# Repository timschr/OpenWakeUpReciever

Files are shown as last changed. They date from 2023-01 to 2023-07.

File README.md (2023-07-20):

# README - Open Wake-Up Receiver (WuR) Platform

## Table of Contents
1. [Introduction](#introduction)
2. [Getting Started](#getting-started)
3. [Documentation](#documentation)
4. [Usage](#usage)
5. [Contributing](#contributing)
6. [FAQ](#faq)
7. [License](#license)
8. [Acknowledgments](#acknowledgments)

## Introduction

Welcome to the world of Wake-up Receivers (WuRs)! 

Have you ever wished to have a tiny, ultra-low power device that can awaken your sensor nodes from sleep mode only when needed, saving power and reducing latency? WuR is the game-changer you've been waiting for!
The wake-up receiver's job is to keep a power-hungry device asleep and only wake it up when it's needed, saving energy.

This technology can be the brain of your next IoT project, enabling wireless sensor networks to function efficiently, conserve energy, and respond swiftly. From setting up a smart home system that wakes up when you're near, to implementing precision agriculture that responds to real-time changes in the environment, WuR opens up a world of possibilities.

WuR_Mac

## How to get started
Just head over to the [Hardware Guide](hardware/README.md) and go step by step from there.
If you feel at any point that your need more background or explation why thing where done the way the are, please refer to the [thesis](master_thesis_open_wake_up_receiver.pdf) this project is based on.

## How to get done

#### 1. Order Your PCB

The first step is to order your PCB (Printed Circuit Board). This will serve as the base for your wake-up receiver, where you'll attach and connect all your components. 

#### 2. Acquire Necessary Parts

Next, you'll need to gather all the other parts required for this project. This includes an 868MHz antenna a nano power comparator, and the PIC12LF1552 Microcontroller Unit (MCU). You can refer to the [Hardware Guide](hardware/README.md) for a more detailed list and where to get these parts.

#### 3. Assemble Your Receiver

Once you have your PCB and all the necessary parts, you can start putting your receiver together. Attach the components to your PCB and connect them according to the circuit design. Remember to double-check all your connections to ensure they're correct and secure.

#### 4. Program the MCU

With your circuit assembled, it's time to program your MCU. You'll need to flash the provided software onto the PIC12LF1552 using suitable PIC microcontroller programming software. More details on how to do this can be found in the [Software Guide](software/README.md).

#### 5. Acquire a Transmitter

Finally, you'll need a transmitter capable of sending OOK (On-Off Keying) signals at 868MHz. This will be used to send the wake-up signal to your receiver. The only requirements are that the transmitter can operate at this frequency and use OOK modulation.

### Prerequisites

#### Hardware:
  - PCB (Printed Circuit Board)
  - All the parts
  - 868 OOK Tranceiver
  - Breadboard
    
#### Tools:
- PICKit3: Programming to for PIC microcontroller. With some effort you can also use a simple arduino for this. Explaine e.g. here [https://github.com/jaromir-sukuba/a-p-prog])
- Soldering iron: You'll need this to attach components to your PCB. Not needed when you order the PCB preassembled.
- (Oscilloscope: This is optional but recommended for analyzing the signals in your circuit.)
- (NanoVNA: This is optional but handy to analyze the quality of the mathching network)

## Contributing

We warmly welcome contributions to this project. If you'd like to contribute, please fork the repository and make your changes. Then create a Pull Request to get your changes merged and reviewed.

We have a few guidelines for contributing, please check them out here: [CONTRIBUTING.md](./CONTRIBUTING.md)

## License

This project is licensed under the MIT License - see the [LICENSE.md](LICENSE.md) file for details

## Acknowledgments

I'd like to acknowledge the contributions of my academic advisors and the open-source community that has been pivotal in making this project what it is.

---

To create a detailed `CONTRIBUTING.md` file, include sections like:

1. Code of Conduct
2. How to report bugs or request features
3. How to set up the development environment
4. Code style guides
5. How to submit a Pull Request
6. What to expect after a Pull Request is submitted

In the `LICENSE.md` file, provide the full text of the license. If you're using MIT, you can find that [here](https://choosealicense.com/licenses/mit/).

The FAQ section should be updated as users interact with your project. Start with questions you think will be common, then add more as they come up.

Remember, READMEs are often the first thing people see when they come to your project, so make it engaging, informative, and welcoming.

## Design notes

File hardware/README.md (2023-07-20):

# Hardware Guide

This guide will walk you through the hardware aspects of creating your wake-up receiver, from understanding impedance matching, to ordering and assembling your PCB.

## Background: Impedance Matching

Impedance matching is a crucial concept in electronics that helps ensure maximum power transfer between components. In the context of our wake-up receiver, we need to ensure that the antenna and the circuitry on the PCB have the same impedance to prevent signal reflection and loss.  Trace width for the transmission line can be calculated with the [JLCPCB Impedance Caclulator](https://jlcpcb.com/pcb-impedance-calculator/) for different materials.

The need for accurate impedance matching is why there isn't much room for variations in the PCB design. Trace width, PCB material, thickness, and the number of layers all play a part in determining the overall impedance. We've chosen a 4-layer PCB as it offers easier impedance control.

## Transmitter

While our wake-up receiver (WuR) is all about listening for specific signals, it's important to remember that we also need a device to send these wake-up signals. 

Any device that supports On-Off Keying (OOK) at 868MHz could be used as a transmitter. In my project, I opted for the RFM95W module. What's really neat about this module is its support for LoRa, a low-power, long-range communication protocol. This could open up some fascinating possibilities, such as setting up a remote sensor network miles away via LoRa, and using WuRs for local communication.

Specifically, I used the [RFM95W shield for the Arduino Uno by Draguino](https://github.com/jgromes/RadioLib), which worked perfectly. This shield integrates well with the Arduino Uno, making it easy to create and transmit signals to our WuR.

An added bonus of the RFM95W module is that it's supported by the RadioLib library. If you're interested in doing more radio work with Arduino, I highly recommend checking out [RadioLib](https://github.com/jgromes/RadioLib). It's an incredibly helpful resource, packed full of tools and examples for various types of radio communication.

## Ordering Your PCB
With that said, let's start building. You will first need to order your PCB based on the provided [production files](production/). This guide will walk you through how to order it from JLCPCB, but you can also choose a different manufacturer as long as they have similar material characteristics.

### How to Order from JLCPCB:

1. Go to the [JLCPCB website](https://jlcpcb.com/)
2. Click on "Quote Now" or "Order Now"
3. In the new page, click on "Add your Gerber file" and upload the provided Gerber file
4. Scroll down to the "High-spec Options" and choose "Impedance Control: Yes"
5. Under "Layer stackup", select "JLC04161H-7628"

Then proceed with your order following the website's instructions.

## Ordering Parts

Next, you will need to order the other parts required for this project. These can be found at vendors like [Mouser](https://www.mouser.com/) or [Digikey](https://www.digikey.com/). The list of parts needed will be provided.

#### Parts List for 1 WuR
For the PCB:
Number of parts. Describtion, Spezification, Package
- 1 Inductor 2.2nH 0805
- 1 Inductor 3.3nH 0805
- 1 Capacitor 3.7pF 0805
- 1 Capacitor 5pF 0805
- 1 Capacitor 22pF 0805
- 1 Diode SMS7630-005LF
- 1 Diode XXX SMA
- 1 Resistor 2.2k 0805
- 1 Resistor XXX 0805
- 1 Capacitor 100n
- 1 Comparator TLV7031 SOT-23-5

For the breadboard:
- breadboard
- jumper wires
- PIC12LF1552

## Assembly

If you don't already have an 868MHz OOK transmitter, you'll need to purchase one. Once you have all your parts and your PCB, you can begin to put everything together on the breadboard.

Now, with your hardware assembled, you can move on to flashing the software onto your microcontroller. Please refer to the [Software Guide](../software/README.md) for instructions on how to do this.

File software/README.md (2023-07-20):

# Software Guide

This guide will walk you through how to upload the `wur_pic12lf1552_main.c` program to your PIC12LF1552 microcontroller using a PicKit3 programmer and MPLAB X IDE.

## Prerequisites 

Before starting, ensure that you have the following:

1. **MPLAB X IDE** installed on your computer. If you don't have it, you can download it from the [Microchip website](https://www.microchip.com/en-us/development-tools-tools-and-software/mplab-x-ide).

2. **PicKit3** programmer. This is the tool we'll use to transfer the program onto your microcontroller.

3. **wur_pic12lf1552_main.c** file. This is the program that will run on your PIC12LF1552 microcontroller.

## Steps 

Follow the steps below to upload the software:

1. **Connect Your PicKit3 Programmer**: Connect the PicKit3 programmer to your computer via USB. Then, connect the PicKit3 to your PIC12LF1552 microcontroller on your breadboard or PCB, ensuring that the ICSP (In-Circuit Serial Programming) pins line up correctly.

2. **Open MPLAB X IDE**: Launch the MPLAB X IDE software on your computer.

3. **Create a New Project**: Go to `File -> New Project`. Choose `Microchip Embedded -> Standalone Project` and click `Next`.

4. **Select Device**: In the dropdown menu, select `PIC12LF1552` and click `Next`.

5. **Select Tool**: Choose `PicKit3` in the dropdown menu and click `Next`.

6. **Select Compiler**: Choose the compiler you have installed. If you have none, download and install the `XC8` compiler from Microchip's website. Once installed, select it and click `Next`.

7. **Name and Choose Project Location**: Give your project a name and choose a location on your computer to save it. Click `Finish`.

8. **Add Your Source Code File**: Right-click on `Source Files` in the Project Window and choose `New -> main.c`. Copy the contents of `wur_pic12lf1552_main.c` into this new file. Save the file.

9. **Build the Project**: Click on the `Build` button (hammer icon) to compile your code. If the build is successful, you should see a `BUILD SUCCESSFUL` message in the Output Window.

10. **Program the MCU**: Click on the `Make and Program Device Main Project` button (the icon with an arrow pointing towards the chip) to upload the compiled program onto your PIC12LF1552 microcontroller.

If you encounter any issues, refer to the MPLAB X IDE's troubleshooting guide or Microchip's support forums.

## Understanding the Software
In this program, we're using a simple two-channel system to handle our wake-up signals that are connected to the `RA0` pin (data) and `RA2` pin (preamble). The first channel, `RA2`, is used to detect when a signal starts - this is called the preamble. When `RA2` detects a signal, it activates the second channel, `RA0`.

`RA0` is where we receive the actual data of the signal. Once `RA2` has detected a signal and activated `RA0`, the program starts measuring the time between signals on `RA0`. This is our data - specifically, it's an 'address' that tells the microcontroller whether it should wake up or ignore the signal.

## Adapting the code
Keeping the program simple is critical because we're working with a small 8-bit microcontroller. This microcontroller isn't very powerful, so if the program gets too complex, it might start to slow down or experience delays. That's why we're just using these two channels and a timer to handle our wake-up signals.

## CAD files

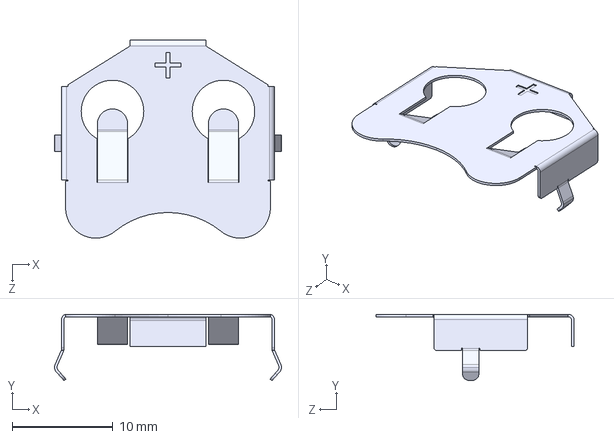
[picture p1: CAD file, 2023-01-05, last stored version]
ESP32-Power-Board/part_libs/BAT-HLD-005-THM/BAT-HLD-005-THM.step
22.5 x 6.59 x 19.6 mm

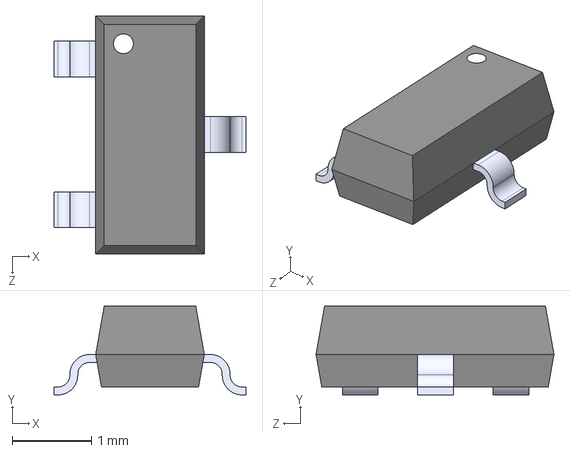
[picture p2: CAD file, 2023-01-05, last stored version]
ESP32-Power-Board/part_libs/DMP1045U/DMP1045U.step
2.42 x 1.12 x 3.00 mm

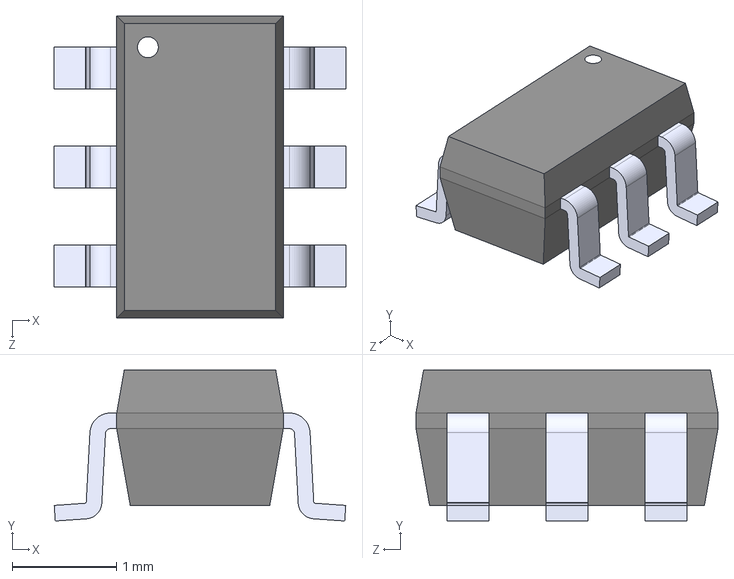
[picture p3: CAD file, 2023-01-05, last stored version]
ESP32-Power-Board/part_libs/DW01A/DW01A--3DModel-STEP-56544.STEP
2.80 x 1.45 x 2.90 mm

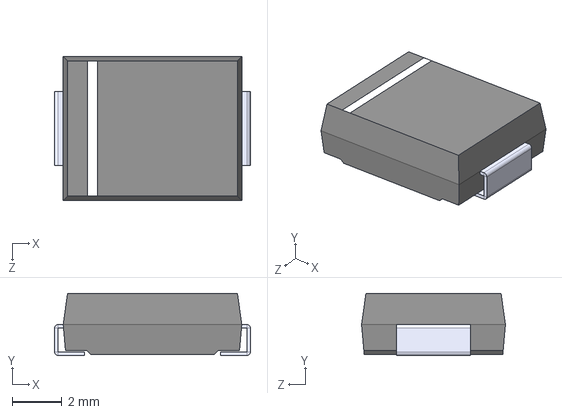
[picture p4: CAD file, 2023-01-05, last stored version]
ESP32-Power-Board/part_libs/SS34/SS34.step
7.90 x 2.50 x 5.80 mm

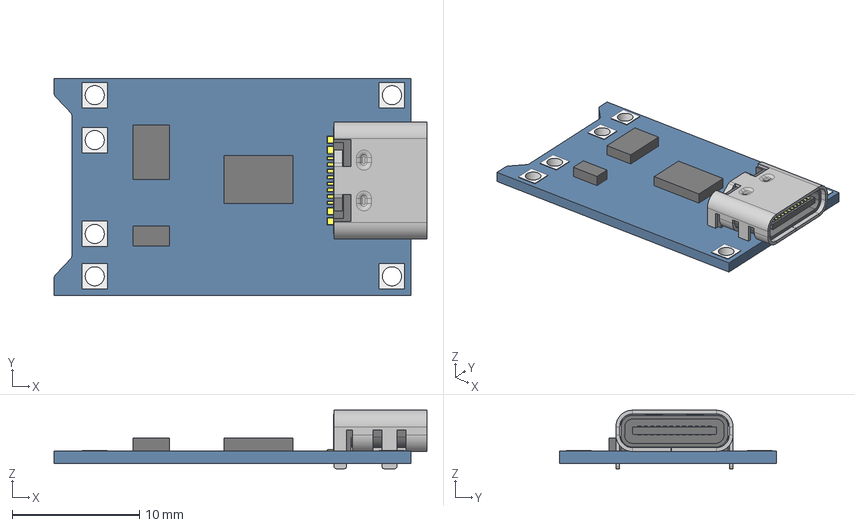
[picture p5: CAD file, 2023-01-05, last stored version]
ESP32-Power-Board/part_libs/TP4056/TP4056.step
29.3 x 17.0 x 4.60 mm

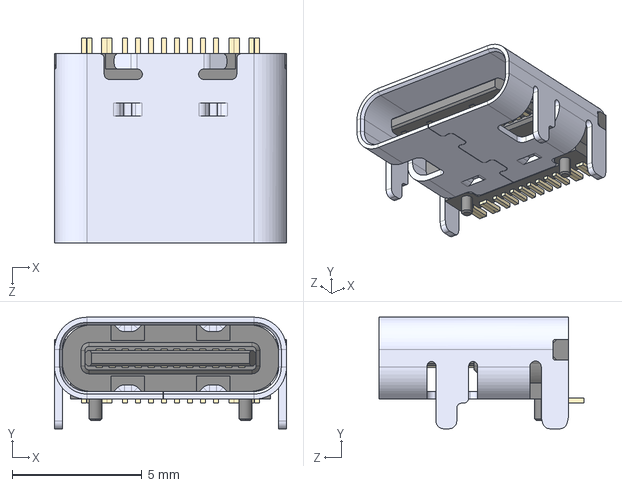
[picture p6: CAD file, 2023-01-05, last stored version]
ESP32-Power-Board/part_libs/TYPE-C-31-M-12/TYPE-C-31-M-12.step
8.94 x 4.30 x 7.90 mm

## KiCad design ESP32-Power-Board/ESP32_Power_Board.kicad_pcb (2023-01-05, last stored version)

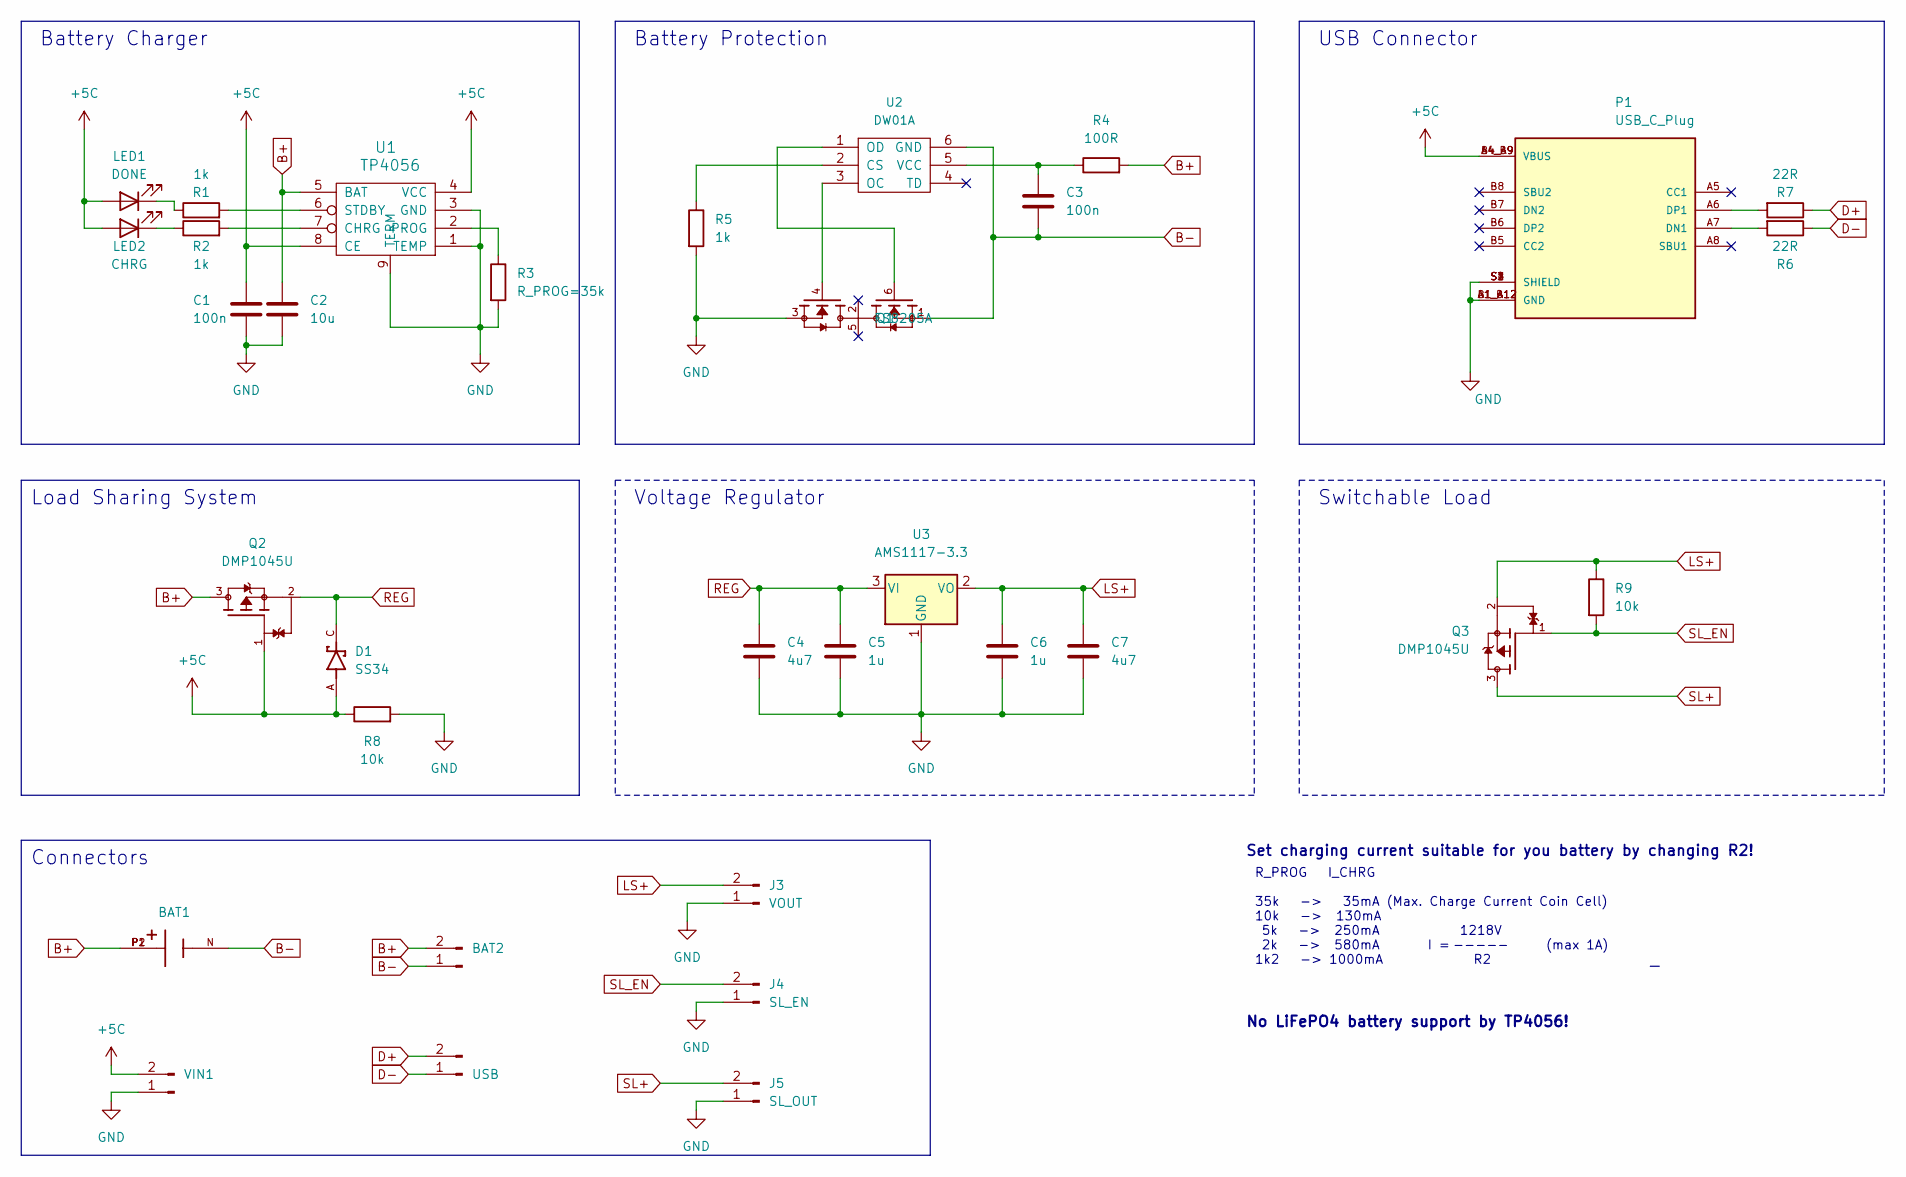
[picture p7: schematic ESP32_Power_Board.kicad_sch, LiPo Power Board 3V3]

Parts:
BAT1: BAT-HLD-005-THM; BAT_BAT-HLD-005-THM; PARTREV A
BAT2: BAT; JST_PH_B2B-PH-K_1x02_P2.00mm_Vertical
C1, C3: 100n; C_0805_2012Metric
C2: 10u; C_0805_2012Metric
C4, C7: 4u7; C_0805_2012Metric
C5, C6: 1u; C_0805_2012Metric
D1: SS34; DIOM7959X265N; PARTREV 31 Aug 2016
J3: VOUT; PinHeader_1x02_P2.54mm_Vertical
J4: SL_EN; PinHeader_1x02_P2.54mm_Vertical
J5: SL_OUT; PinHeader_1x02_P2.54mm_Vertical
LED1: DONE; LED_0805_2012Metric
LED2: CHRG; LED_0805_2012Metric
P1: USB_C_Plug; HRO_TYPE-C-31-M-12; PARTREV 2020.12.08
Q1: FS8205A; SOT95P280X145-6N; PARTREV 1.9
Q2, Q3: DMP1045U; SOT91P240X110-3N; PARTREV 7 - 2
R1, R2, R5: 1k; R_0805_2012Metric
R3: R_PROG=35k; R_0805_2012Metric
R4: 100R; R_0805_2012Metric
R6, R7: 22R; R_0805_2012Metric
R8, R9: 10k; R_0805_2012Metric
U1: TP4056; SOP127P600X175-9N
U2: DW01A; SOT23-6
U3: AMS1117-3.3; SOT-223-3_TabPin2
USB1: USB; PinSocket_1x02_P2.54mm_Vertical
VIN1: +VIN-; PinHeader_1x02_P2.54mm_Vertical

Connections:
+5C: C1.1, D1.A, LED1.2 (A), LED2.2 (A), P1.A4_B9 (VBUS), P1.B4_A9 (VBUS), Q2.1, R8.1, U1.4 (VCC), U1.8 (CE), VIN1.2
B+: BAT1.P1, BAT1.P2, BAT2.2, C2.1, Q2.3, R4.2, U1.5 (BAT)
B-: BAT1.N, BAT2.1, C3.2, Q1.1, U2.6 (GND)
D+: R7.1, USB1.2
D-: R6.1, USB1.1
GND: C1.2, C2.2, C4.2, C5.2, C6.2, C7.2, J3.1, J4.1, J5.1, P1.A1_B12 (GND), P1.B1_A12 (GND), P1.S1 (SHIELD), P1.S2 (SHIELD), P1.S3 (SHIELD), P1.S4 (SHIELD), Q1.3, R3.2, R5.2, R8.2, U1.1 (TEMP), U1.3 (GND), U1.9 (TERM), U3.1 (GND), VIN1.1; also elsewhere on the board
LS+: C6.1, C7.1, J3.2, Q3.2, R9.1, U3.2 (VO)
unnamed: C3.1, R4.1, U2.5 (VCC)
unnamed: LED1.1 (K), R1.1
unnamed: LED2.1 (K), R2.1
unnamed: P1.A6 (DP1), R7.2
unnamed: P1.A7 (DN1), R6.2
unnamed: R1.2, U1.6 (STDBY)
unnamed: R2.2, U1.7 (CHRG)
unnamed 14: R3.1, U1.2 (PROG); also elsewhere on the board
unnamed: R5.1, U2.2 (CS)
unnamed: Q1.6, U2.1 (OD)
unnamed: Q1.4, U2.3 (OC)
REG: C4.1, C5.1, D1.C, Q2.2, U3.3 (VI)
SL+: J5.2, Q3.3
SL_EN: J4.2, Q3.1, R9.2

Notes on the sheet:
Load Sharing System
USB Connector
1218V ----- R2
Switchable Load
Connectors
No LiFePO4 battery support by TP4056!
Battery Protection
Voltage Regulator
R_PROG I_CHRG 35k -> 35mA (Max. Charge Current Coin Cell) 10k -> 130mA 5k -> 250mA 2k -> 580mA I = (max 1A) 1k2 -> 1000mA
Battery Charger
Set charging current suitable for you battery by changing R2!

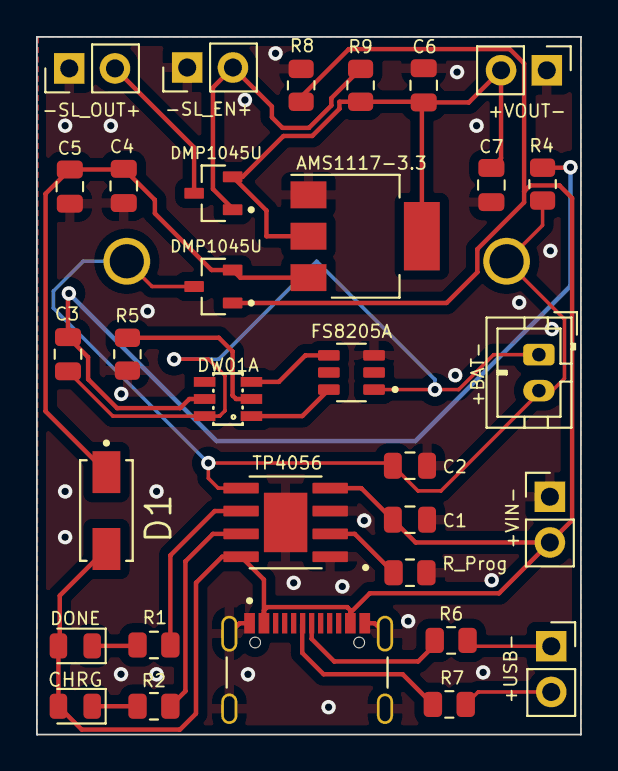
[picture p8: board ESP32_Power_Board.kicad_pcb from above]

Board: 2 copper layers, 30.2 x 38.8 mm, 33 parts (1 on the bottom side), 21 nets.

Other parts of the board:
R_Prog: 35k; R_0805_2012Metric

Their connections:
GND: R_Prog.2; also elsewhere on the board
unnamed 14: R_Prog.1; also elsewhere on the board

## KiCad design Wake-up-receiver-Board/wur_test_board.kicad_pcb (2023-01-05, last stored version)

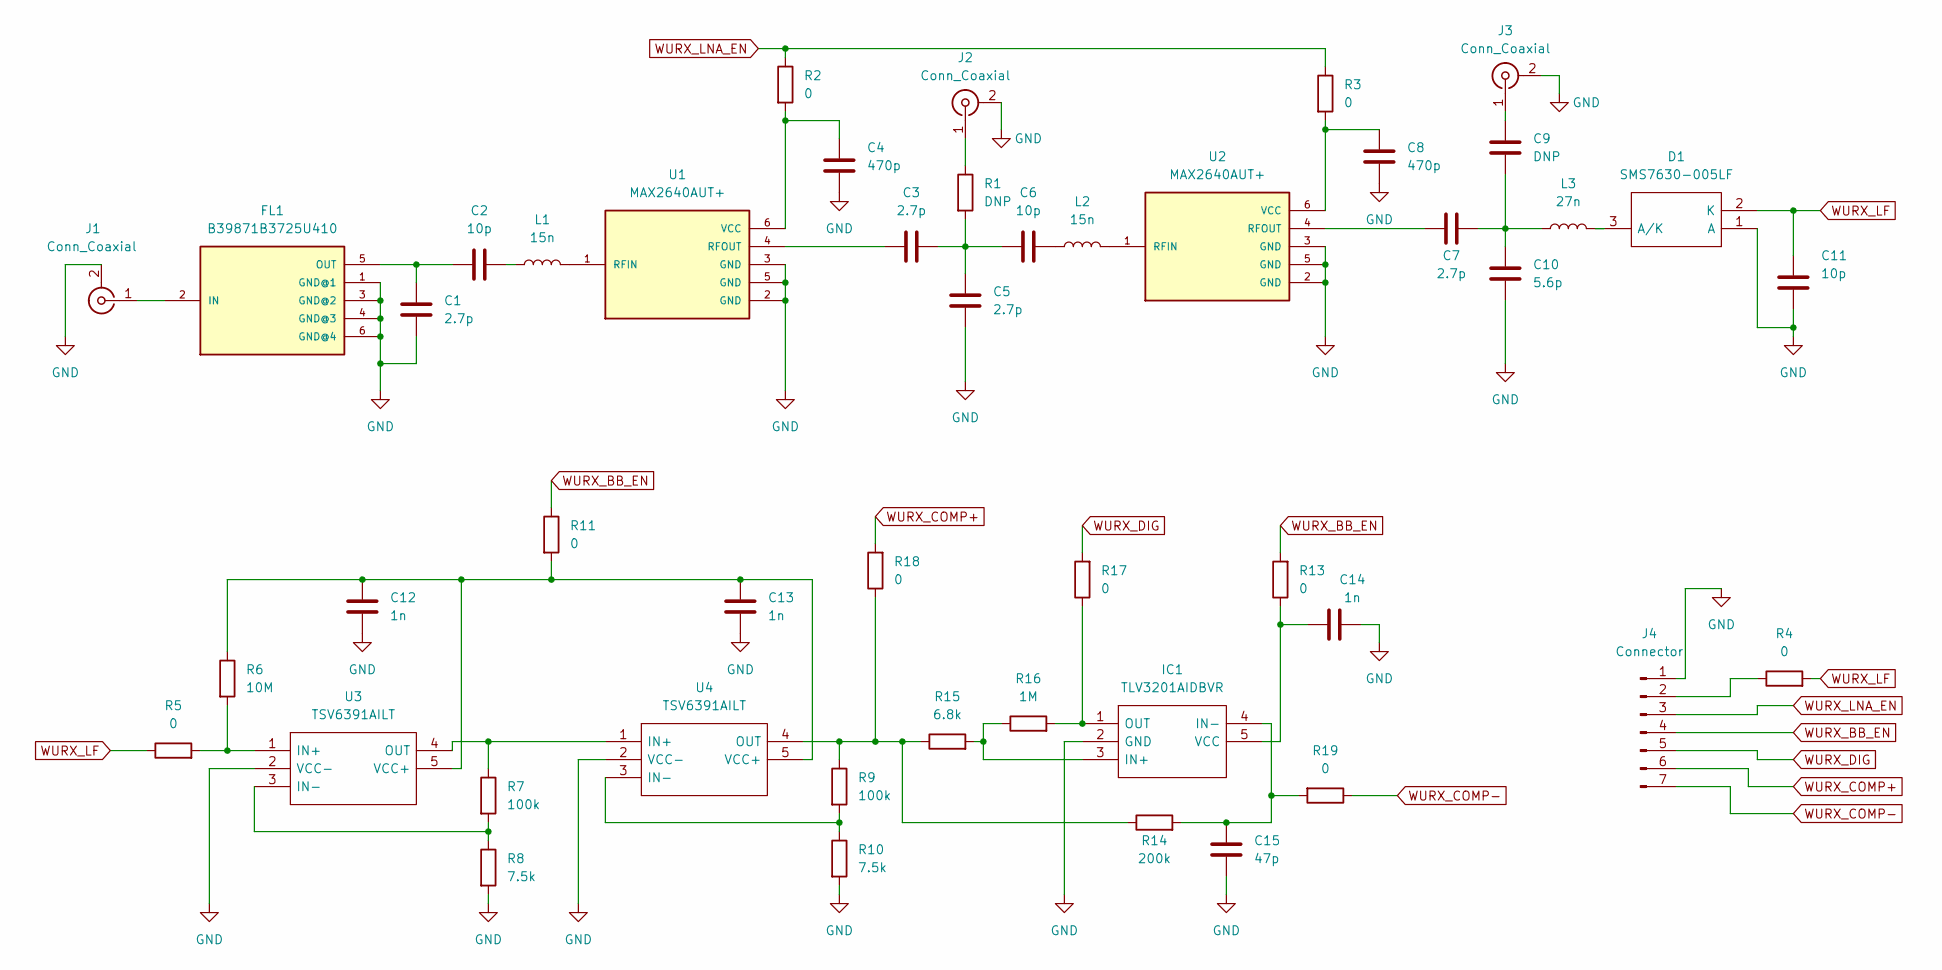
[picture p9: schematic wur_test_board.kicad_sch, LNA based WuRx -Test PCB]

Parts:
C1, C3, C5, C7: 2.7p; C_0805_2012Metric
C2, C6, C11: 10p; C_0805_2012Metric
C4, C8: 470p; C_0805_2012Metric
C9: DNP; C_0805_2012Metric
C10: 5.6p; C_0805_2012Metric
C12, C13, C14: 1n; C_0805_2012Metric
C15: 47p; C_0805_2012Metric
D1: SMS7630-005LF; SOT95P237X112-3N; Manufacturer_Part_Number SMS7630-005LF; Mouser Part Number 873-SMS7630-005LF
FL1: B39871B3725U410; SON120P300X300X110-6N
IC1: TLV3201AIDBVR; SOT95P280X145-5N; Manufacturer_Part_Number TLV3201AIDBVR; Mouser Part Number 595-TLV3201AIDBVR
J1: Conn_Coaxial; SMA_Amphenol_901-143_Horizontal
J2, J3: Conn_Coaxial; BNC_Amphenol_B6252HB-NPP3G-50_Horizontal
J4: Connector; PinHeader_1x07_P2.54mm_Vertical
L1, L2: 15n; L_0805_2012Metric
L3: 27n; L_0805_2012Metric
R1: DNP; R_0805_2012Metric
R2, R3, R4, R5, R11, R13, R17, R18, R19: 0; R_0805_2012Metric
R6: 10M; R_0805_2012Metric
R7, R9: 100k; R_0805_2012Metric
R8, R10: 7.5k; R_0805_2012Metric
R14: 200k; R_0805_2012Metric
R15: 6.8k; R_0805_2012Metric
R16: 1M; R_0805_2012Metric
U1, U2: MAX2640AUT+; SOT95P280X145-6N
U3, U4: TSV6391AILT; SOT95P280X145-5N; Manufacturer_Part_Number TSV6391AILT; Mouser Part Number 511-TSV6391AILT

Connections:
GND: C1.1, C4.2, C5.2, C8.2, C10.2, C11.1, C12.2, C13.1, C14.2, C15.2, D1.1 (A), FL1.1 (GND@1), FL1.3 (GND@2), FL1.4 (GND@3), FL1.6 (GND@4), IC1.2 (GND), J1.2 (Ext), J2.2 (Ext), J3.2 (Ext), J4.1, R8.2, R10.2, U1.2 (GND), U1.3 (GND), U1.5 (GND), U2.2 (GND), U2.3 (GND), U2.5 (GND), U3.2 (VCC-), U4.2 (VCC-)
unnamed: C1.2, C2.1, FL1.5 (OUT)
unnamed: C2.2, L1.1
unnamed: C3.1, U1.4 (RFOUT)
unnamed: C3.2, C5.1, C6.1, R1.2
unnamed: C4.1, R2.2, U1.6 (VCC)
unnamed: C6.2, L2.1
unnamed: C7.2, U2.4 (RFOUT)
unnamed: C8.1, R3.2, U2.6 (VCC)
unnamed: C9.1, J3.1 (In)
unnamed: C7.1, C9.2, C10.1, L3.1
unnamed: C12.1, C13.2, R6.1, R11.2, U3.5 (VCC+), U4.5 (VCC+)
unnamed: C14.1, IC1.5 (VCC), R13.1
unnamed: C15.1, IC1.4 (IN-), R14.2, R19.2
unnamed: D1.3 (A/K), L3.2
unnamed: FL1.2 (IN), J1.1 (In)
unnamed: IC1.1 (OUT), R16.2, R17.1
unnamed: IC1.3 (IN+), R15.2, R16.1
unnamed: J2.1 (In), R1.1
unnamed: J4.2, R4.1
unnamed: L1.2, U1.1 (RFIN)
unnamed: L2.2, U2.1 (RFIN)
unnamed: R5.2, R6.2, U3.1 (IN+)
unnamed: R7.1, U3.4 (OUT), U4.1 (IN+)
unnamed: R7.2, R8.1, U3.3 (IN-)
unnamed: R9.2, R10.1, U4.3 (IN-)
unnamed: R9.1, R14.1, R15.1, R18.1, U4.4 (OUT)
WURX_BB_EN: J4.4, R11.1, R13.2
WURX_COMP+: J4.6, R18.2
WURX_COMP-: J4.7, R19.1
WURX_DIG: J4.5, R17.2
WURX_LF: C11.2, D1.2 (K), R4.2, R5.1
WURX_LNA_EN: J4.3, R2.1, R3.1

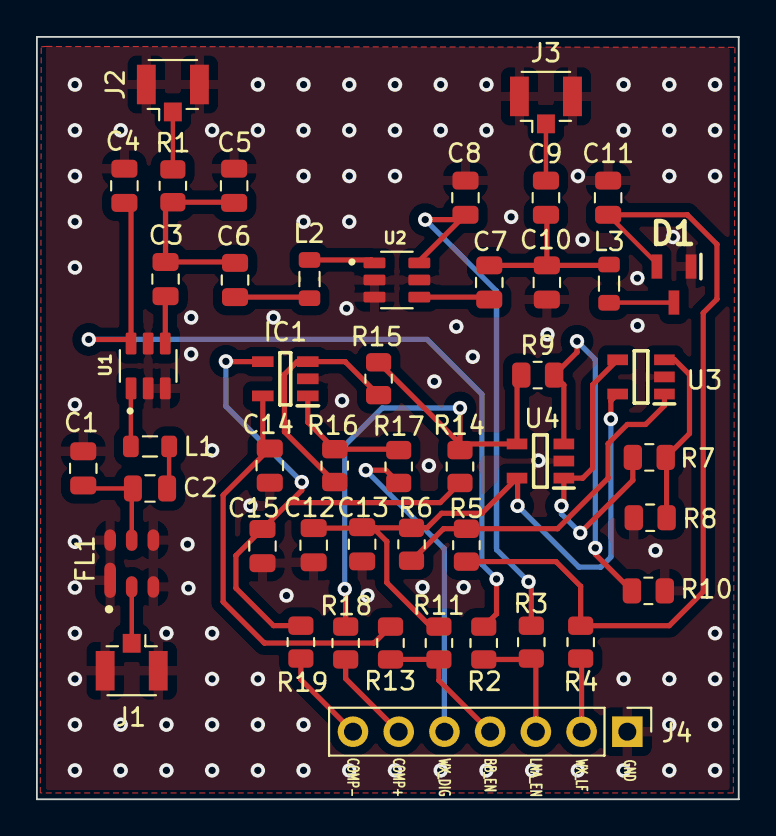
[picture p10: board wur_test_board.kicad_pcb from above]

Board: 4 copper layers, 39.0 x 42.4 mm, 47 parts (0 on the bottom side), 33 nets.

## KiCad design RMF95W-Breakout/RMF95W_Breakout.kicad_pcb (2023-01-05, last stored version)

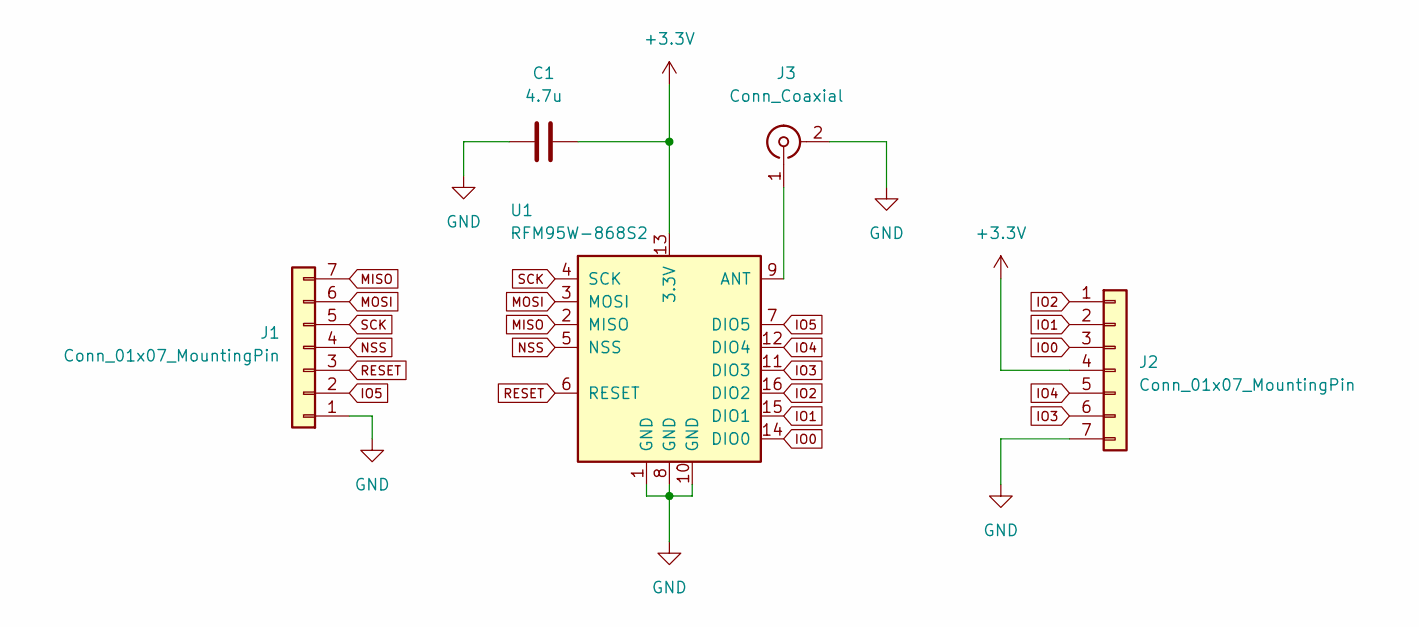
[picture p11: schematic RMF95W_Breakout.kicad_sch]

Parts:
C1: 4.7u; C_0805_2012Metric
J1, J2: Conn_01x07_MountingPin; PinHeader_1x07_P2.54mm_Vertical
J3: Conn_Coaxial; U.FL_Hirose_U.FL-R-SMT-1_Vertical
U1: RFM95W-868S2; HOPERF_RFM9XW_SMD

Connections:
+3.3V: C1.2, J2.4, U1.13 (3.3V)
GND: C1.1, J1.1, J2.7, J3.2 (Ext), U1.1 (GND), U1.8 (GND), U1.10 (GND)
IO0: J2.3, U1.14 (DIO0)
IO1: J2.2, U1.15 (DIO1)
IO2: J2.1, U1.16 (DIO2)
IO3: J2.6, U1.11 (DIO3)
IO4: J2.5, U1.12 (DIO4)
IO5: J1.2, U1.7 (DIO5)
MISO: J1.7, U1.2 (MISO)
MOSI: J1.6, U1.3 (MOSI)
NSS: J1.4, U1.5 (NSS)
unnamed: J3.1 (In), U1.9 (ANT)
RESET: J1.3, U1.6 (RESET)
SCK: J1.5, U1.4 (SCK)

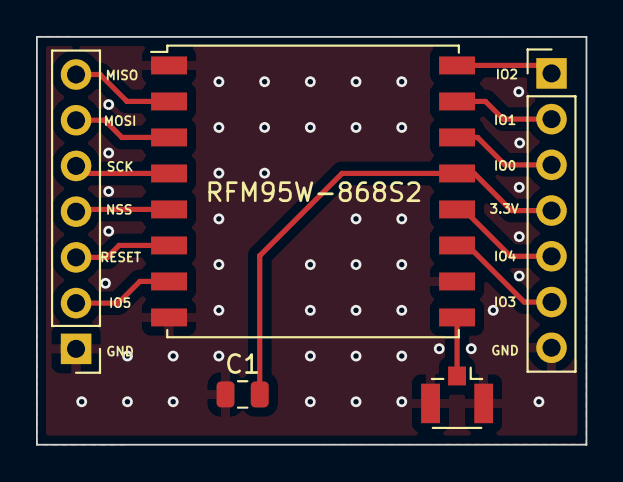
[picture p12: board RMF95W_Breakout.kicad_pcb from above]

Board: 4 copper layers, 30.5 x 22.7 mm, 5 parts (0 on the bottom side), 14 nets.
